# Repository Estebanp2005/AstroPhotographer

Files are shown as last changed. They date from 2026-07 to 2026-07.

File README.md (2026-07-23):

# AstroPhotographer

*Read this in other languages: [Español](README_es.md)*

**AstroPhotographer** is an advanced, automated intervalometer specifically designed for astrophotography. Based on the ESP8266 microcontroller, this device allows precise control of the shutter and focus of DSLR or Mirrorless cameras through a relay system, providing comprehensive management for long photographic sessions.

## Main Features

* **Precise Control:** Management of shutter speeds and intervals between photos via a 2-channel relay module.
* **Profile Management:** Non-volatile storage of up to 6 customizable shooting profiles (name, shutter speed, interval, and photo limit).
* **Intuitive User Interface:** Menu navigation using a rotary encoder and real-time visualization on a 16x2 LCD display (I2C).
* **Global Statistics:** Persistent recording in EEPROM memory (LittleFS/Preferences) of the total historical photos captured and the total running time of the device.
* **Acoustic Notifications:** Integration of an active buzzer for sequence completion alerts.
* **Adaptive Logic:** Software compensation for native reverse logic found in standard relay modules, and hardware/software managed debounce for the rotary encoder.

---

## Hardware Requirements

* ESP8266 Microcontroller (NodeMCU V2/V3 or Wemos D1 Mini).
* 16x2 LCD Display with I2C adapter module.
* Rotary Encoder (Standard 5-pin module or "bare" encoder with internal Pull-Up resistors enabled via software).
* 2-Channel Relay Module (Reverse Logic in this specific build).
* Active Buzzer.
* Camera trigger cable compatible with your specific camera port.
* Logic Level Shifter (3.3V to 5V).

---

## Wiring Schematic (Pinout)

### Hardware Wiring Diagram
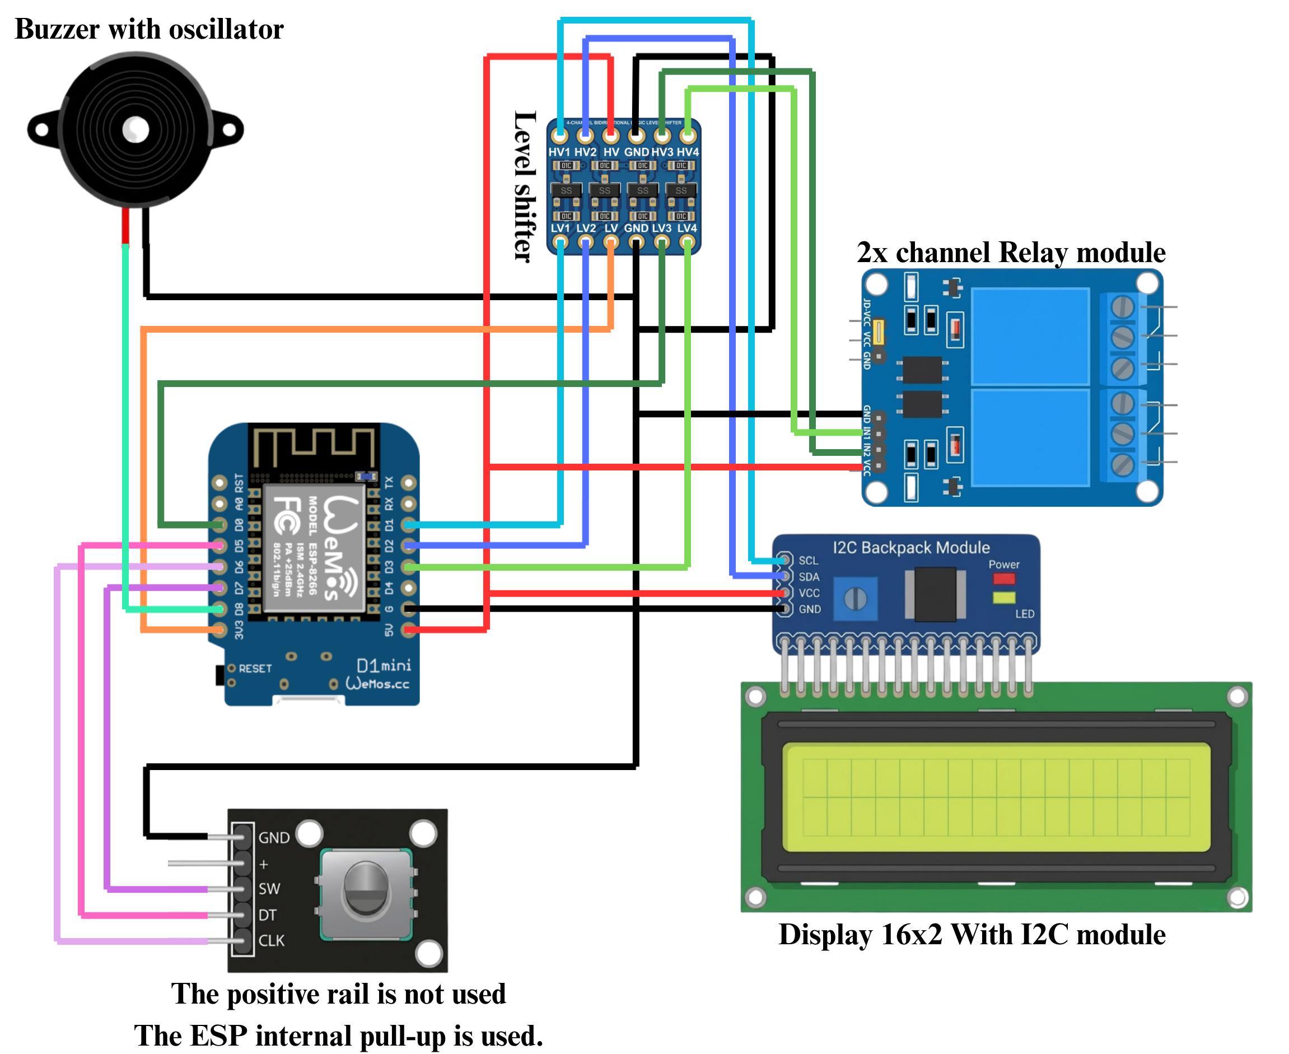
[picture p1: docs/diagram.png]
AstroTracker wiring diagram


### Canon camera jack connection
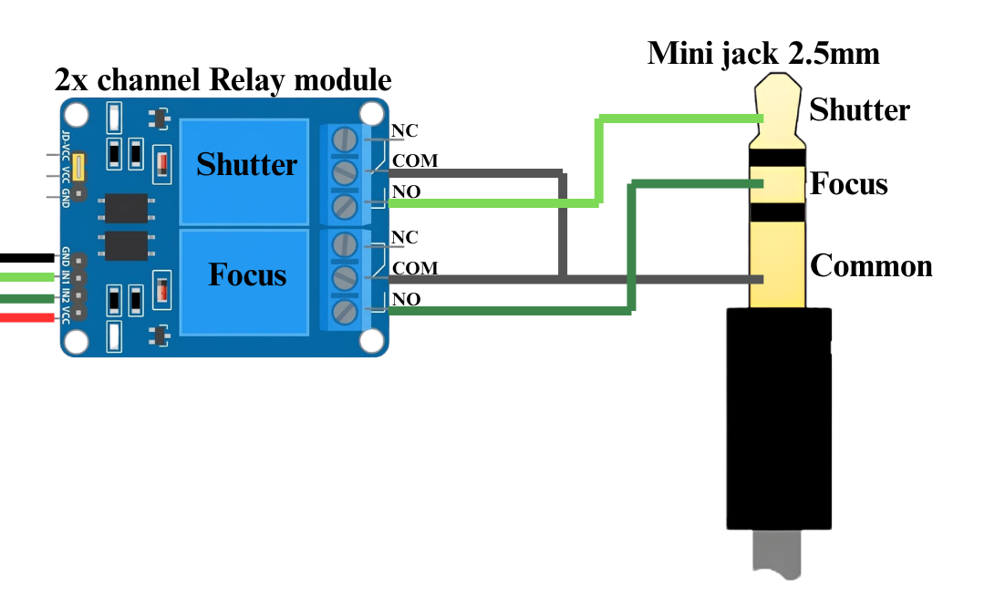
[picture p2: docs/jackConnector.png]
Canon camera jack connection


The following table describes the connection of the peripherals to the ESP8266 GPIO pins according to the firmware configuration:

| Component | Component Pin | ESP8266 Pin |
| :--- | :--- | :--- |
| **LCD Display (I2C)** | SCL | D1 |
| | SDA | D2 |
| **Camera Relays** | Focus IN | D0 |
| | Shutter IN | D3 |
| **Rotary Encoder** | Pin A (DT) | D5 |
| | Pin B (CLK) | D6 |
| | Switch (SW) | D7 |
| **Buzzer**| Positive (VCC/IN) | D8 |

> **Note:** Ensure proper power supply (VCC 3.3V/5V and GND) to the LCD, rotary encoder, and relay module using the board's power outputs or an external regulated power source.

### Hardware assembly
My hardware assembly
| **Perfboard (Top View)** | **Perfboard (Soldering)** | **Case Mounting (1)** |
| :---: | :---: | :---: |
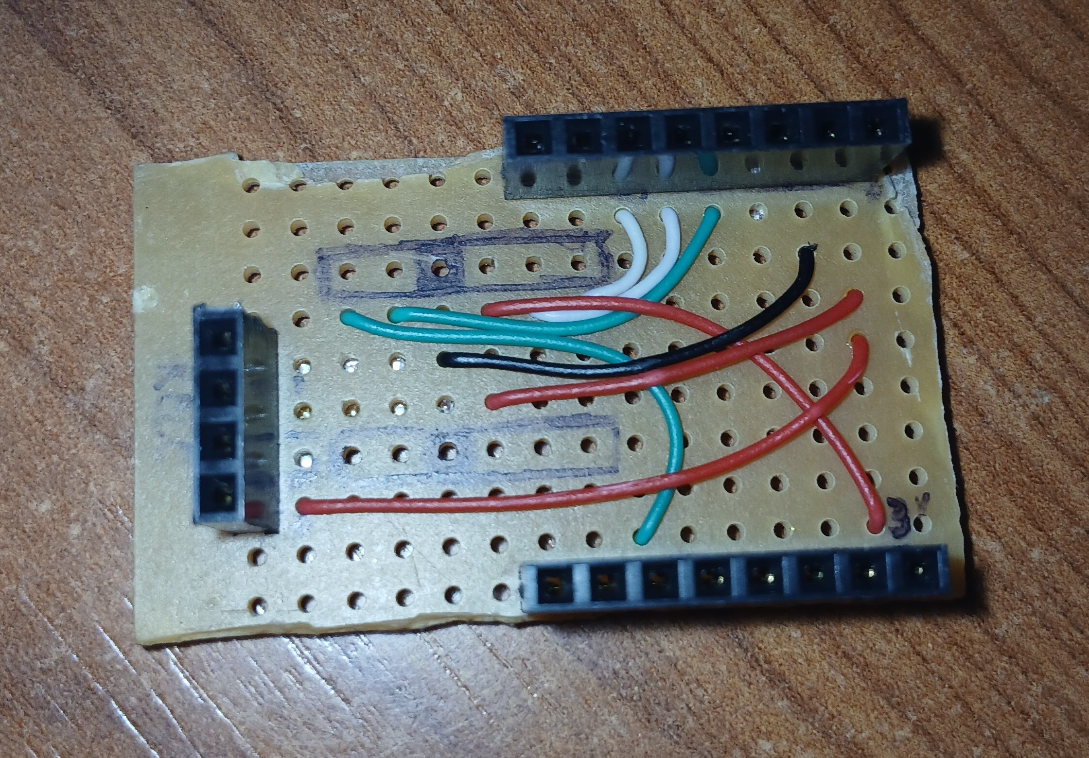
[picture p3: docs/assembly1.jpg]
Top View
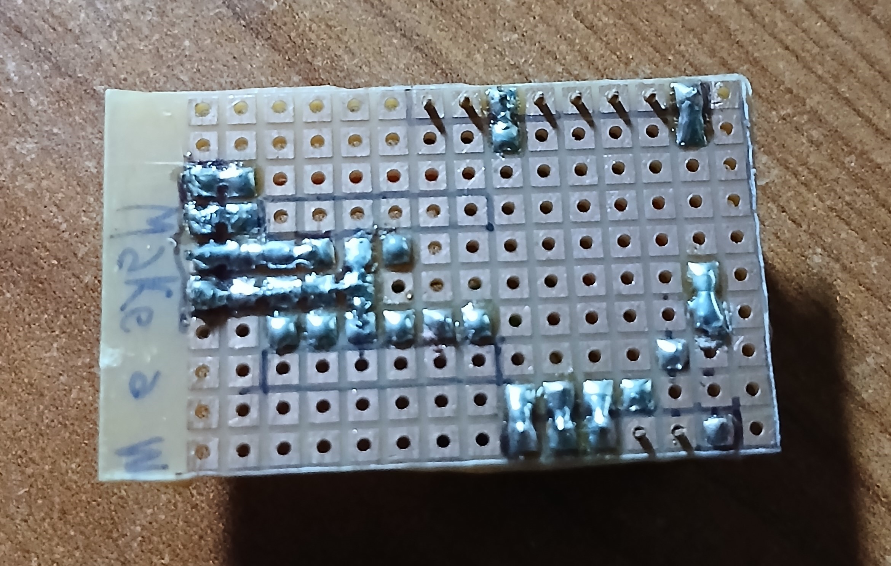
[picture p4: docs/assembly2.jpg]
Soldering
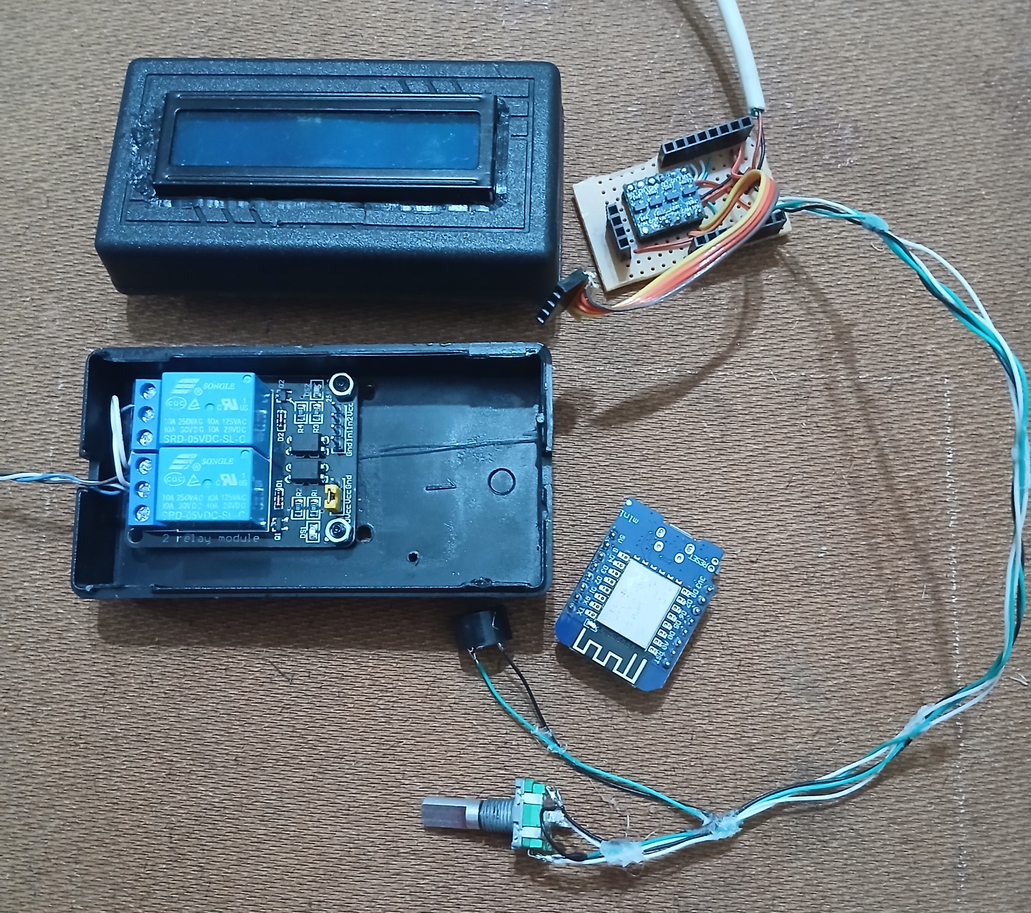
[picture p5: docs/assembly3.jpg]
Layout
|  |  |  |
| **Case Mounting (2)** | **Case Mounting (3)** | **Final Assembly** |
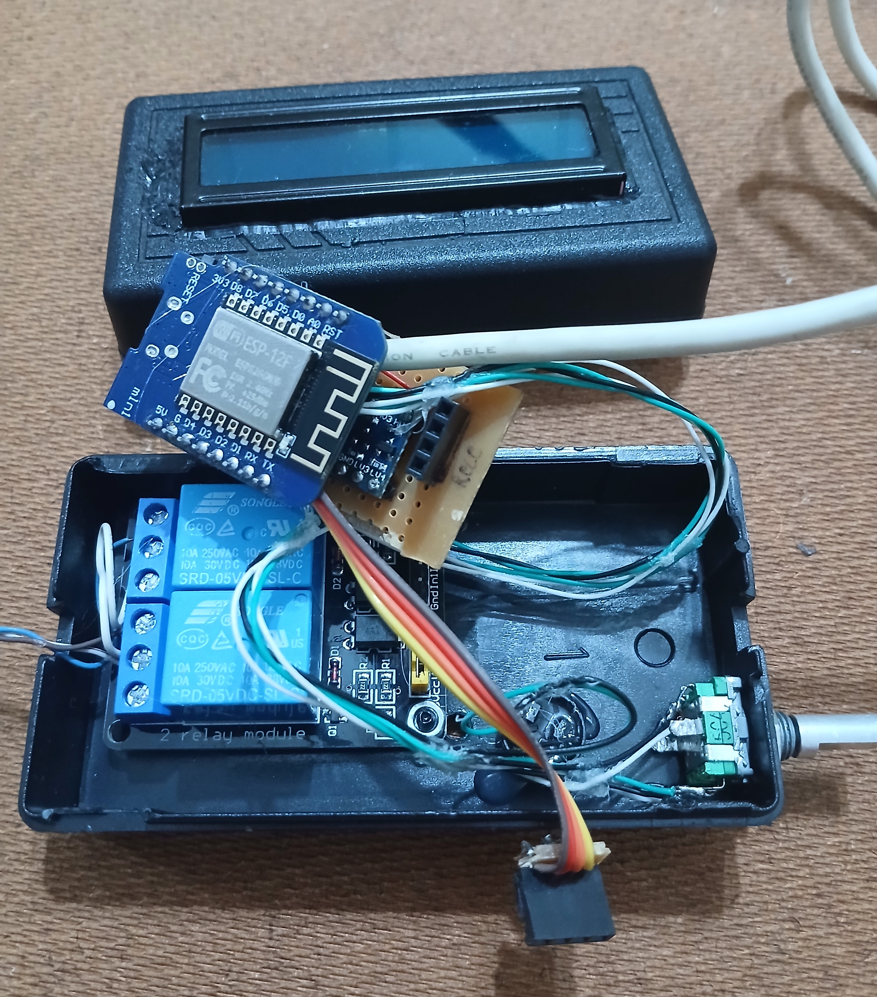
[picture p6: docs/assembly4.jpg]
Mounting 1
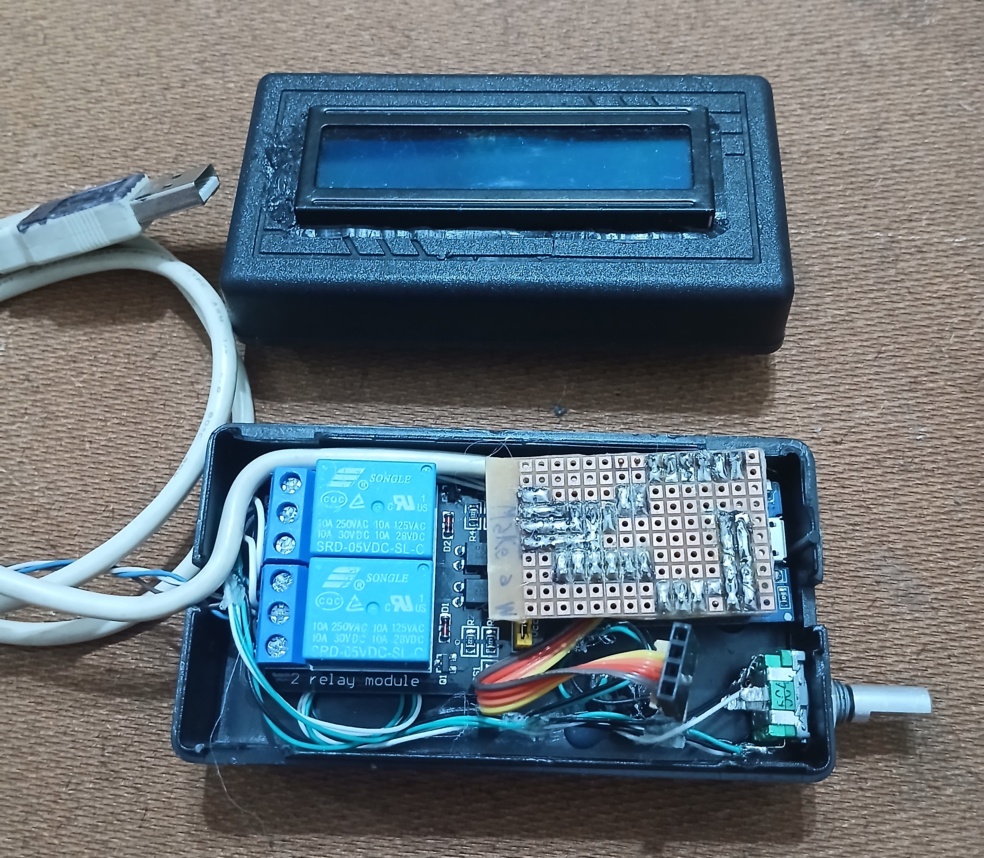
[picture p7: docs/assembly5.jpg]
Mounting 2
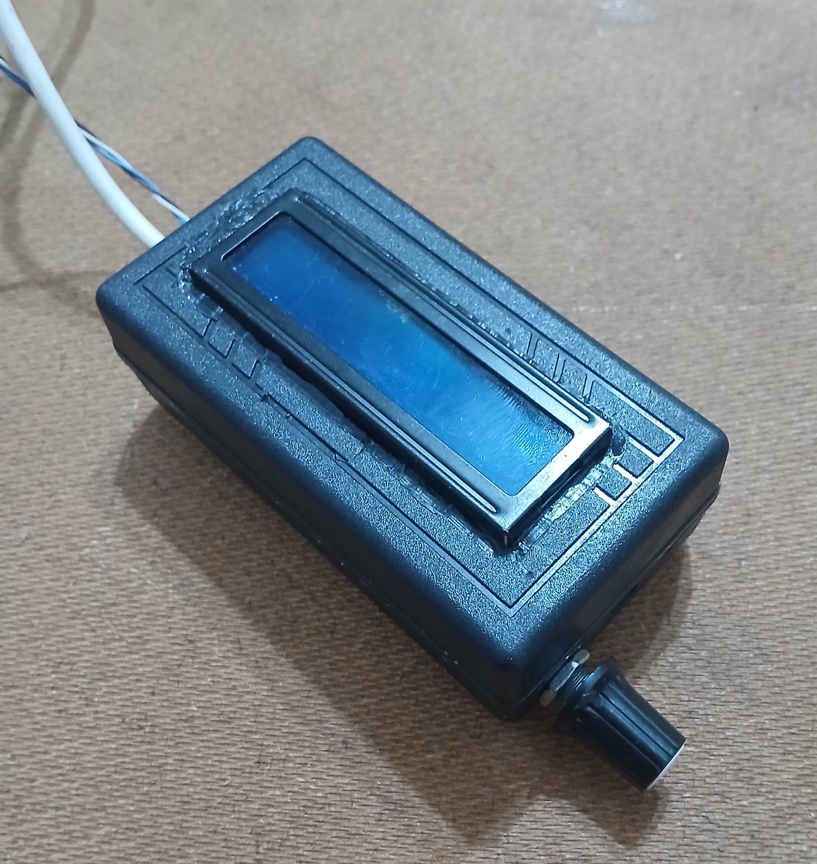
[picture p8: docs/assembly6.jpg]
Final
|  |  |  |

> **Author's note:** I know, this is a bit of a mess; I'm working on a future version that uses Bluetooth instead of a display. Any help is welcome.
---

## Software Dependencies & Libraries

To compile this project in the Arduino IDE, you must install the ESP8266 board support and the following libraries:

1. **[LiquidCrystal_I2C](https://github.com/markub3327/LiquidCrystal_I2C)** (v2.0.0) by Martin Kubovčík / Frank de Brabander: For display management.
2. **[Ai Esp32 Rotary Encoder](https://github.com/igorantolic/ai-esp32-rotary-encoder)** (v1.7) by Igor Antolic: For asynchronous reading and hardware acceleration of the encoder. *(Note: Fully compatible with ESP8266 despite its name).*
3. **[Preferences](https://github.com/vshymanskyy/Preferences)** (v2.2.2) by Volodymyr Shymanskyy: Used to emulate secure EEPROM writing via the LittleFS file system.

---

## Menu Flowchart

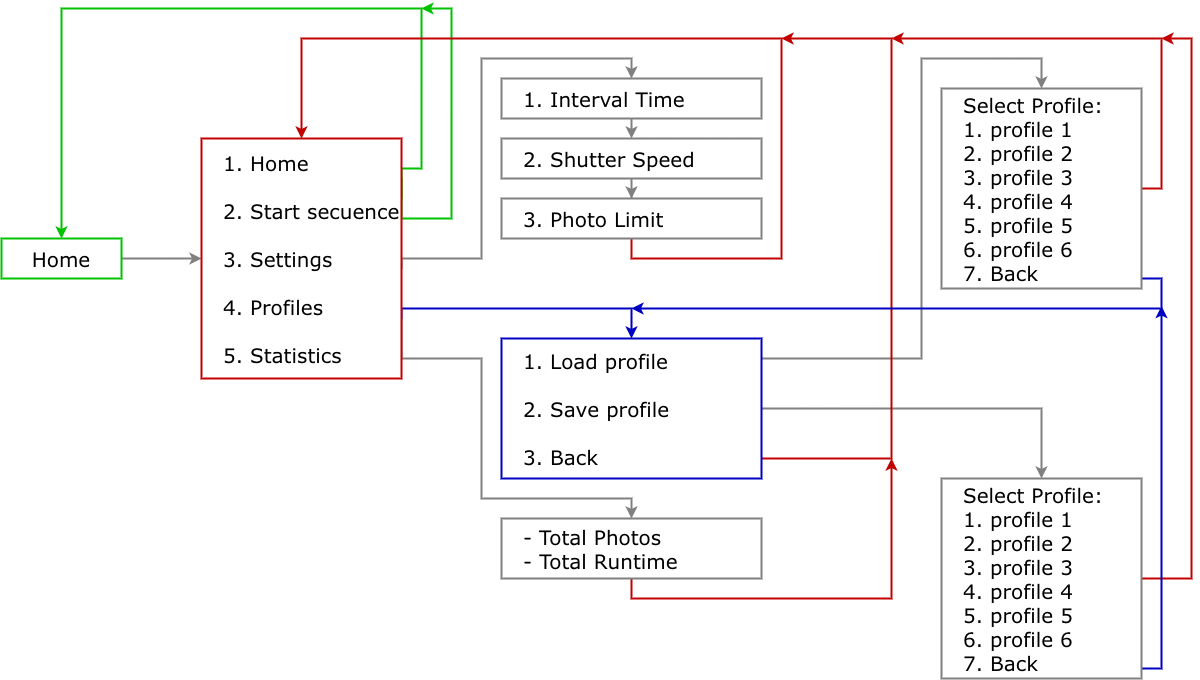
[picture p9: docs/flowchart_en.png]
AstroTracker Menu Flowchart


---

## Usage and Navigation

The system is operated entirely through the rotary encoder (Rotate to navigate/adjust, Press to select).

* **Main Menu:** Access to start sequence, manual configuration, profile loading/saving, and statistics visualization.
* **Start Sequence:** Allows forcing the focus (clockwise rotation) or taking a test shot (counter-clockwise rotation) before starting automation. During the session, the display shows a progress bar and elapsed time.
* **Configuration:** Real-time adjustment of shutter time, interval between photos, and capture limit (0 = infinite).
* **Profiles:** The system allows editing each profile's name character by character for easy identification of photographic setups (e.g., "Milky Way", "Startrails").

---

## Installation

### 1. Board Manager Setup
If you haven't already, add the ESP8266 board support to your Arduino IDE:
* Go to **File > Preferences**.
* In "Additional Boards Manager URLs", add: `https://arduino.esp8266.com/stable/package_esp8266com_index.json`
* Go to **Tools > Board > Boards Manager**, search for `esp8266` and install it.

### 2. Flashing the Firmware
1. Clone this repository.
2. Open the main file `Astrophotographer.ino` in the Arduino IDE.
3. Install the libraries mentioned in the dependencies section via the Library Manager (`Ctrl+Shift+I`).
4. Select your specific ESP8266 board in **Tools > Board**.
5. Compile and upload the firmware to the microcontroller.

---

## License

This project is licensed under the [GNU General Public License v3.0](LICENSE) - see the LICENSE file for details.

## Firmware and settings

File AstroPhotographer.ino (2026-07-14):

/**
 * @file Astrophotographer.ino
 * @brief Main entry point for the AstroTracker firmware.
 * * This file handles the core initialization and the main execution loop
 * of the astrophotography intervalometer. It delegates specific tasks 
 * (input processing, camera relay control, display UI, and memory storage) 
 * to their respective modular components.
 */

#include "Config.h"
#include "Input.h"
#include "Camera.h"
#include "Display.h"
#include "Storage.h"

// --- Global Variables Instantiation ---

/**
 * @brief Tracks the current operational state of the system 
 * (e.g., IDLE, MENU, CONFIG, RUNNING_SEQUENCE).
 */
SystemState currentState = ESTADO_INICIO;

/**
 * @brief Holds the currently active shooting profile loaded in RAM
 * (includes interval, exposure time, photo limit, and profile name).
 */
Perfil perfilActual;

/**
 * @brief Stores the global usage statistics tracked across reboots 
 * (total device runtime and total historical photos taken).
 */
Estadisticas statsGlobales;

/**
 * @brief Navigation index for the primary menu selection.
 */
int menuIndex = 0;

/**
 * @brief Navigation index for the configuration sub-menus.
 */
int configIndex = 0;

// --- Core Functions ---

/**
 * @brief System initialization routine.
 * * Sets up serial communication, initializes the non-volatile storage, 
 * loads the default profile, and prepares all hardware peripherals.
 */
void setup() {
  // Initialize serial communication for debugging purposes
  Serial.begin(115200);
  
  // Initialize LittleFS/Preferences and load historical stats from EEPROM
  initStorage(); 
  
  // Load the default shooting profile (Slot 1 / Index 0) into RAM on startup
  cargarPerfil(0); 
  
  // Initialize hardware peripherals and internal software modules
  initInput();
  initCamera();
  initDisplay();
}

/**
 * @brief Main execution loop.
 * * Continuously polls the encoder input, updates the camera relay logic 
 * based on the active sequence, and refreshes the LCD display UI. 
 * This loop relies on non-blocking state machines.
 */
void loop() {
  updateInput();
  updateCamera();
  updateDisplay();
}

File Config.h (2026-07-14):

/**
 * @file Config.h
 * @brief Global configuration, hardware pinout, data structures, and state machines.
 * * This header acts as the central source of truth for the entire project, 
 * defining hardware connections, UI states, camera sequence states, and data models.
 */

#ifndef CONFIG_H
#define CONFIG_H

#include <Arduino.h>

// --- HARDWARE PINOUT ---

// I2C Display Pins
#define PIN_SCL D1
#define PIN_SDA D2

// Rotary Encoder Pins
#define PIN_ENC_A D5     // DT (Data)
#define PIN_ENC_B D6     // CLK (Clock)
#define PIN_ENC_SW D7    // Switch/Button

// Relay Module & Buzzer Pins
#define PIN_RELAY_SHUTTER D3
#define PIN_RELAY_FOCUS D0
#define PIN_BUZZER D8

// --- DATA STRUCTURES ---

/**
 * @brief Represents a single astrophotography shooting profile.
 */
struct Perfil {
  char nombre[15];          /**< Profile name (max 14 chars + null terminator) */
  float tiempoEntreFotos;   /**< Interval between shots in seconds */
  float tiempoObturacion;   /**< Exposure time in seconds */
  int limiteFotos;          /**< Number of photos to take (0 = infinite) */
};

/**
 * @brief Global device statistics persisted in non-volatile memory (EEPROM/LittleFS).
 */
struct Estadisticas {
  unsigned long totalFotosHistorico; /**< Total photos taken across all sessions */
  unsigned long tiempoTotalFunc;     /**< Total device runtime in milliseconds */
};

// --- STATE MACHINES ---

/**
 * @brief Enumerates the possible states of the user interface (UI).
 */
enum SystemState { 
  ESTADO_INICIO,         /**< Idle / Home screen */
  ESTADO_MENU_PRINCIPAL, /**< Main menu navigation */
  ESTADO_CONFIG,         /**< Adjusting current profile parameters */
  ESTADO_MENU_PERFILES,  /**< Selecting profile management options */
  ESTADO_CARGAR_PERFIL,  /**< Loading a profile from storage */
  ESTADO_GUARDAR_PERFIL, /**< Selecting a slot to save the current profile */
  ESTADO_EDITAR_NOMBRE,  /**< Character-by-character name editing */
  ESTADO_ESTADISTICAS    /**< Viewing historical stats */
};

/**
 * @brief Enumerates the possible states of the camera trigger sequence.
 */
enum CameraState { 
  CAM_DETENIDO,       /**< Sequence stopped / inactive */
  CAM_ESPERA_INICIAL, /**< Initial 3-second delay before starting the sequence */
  CAM_ENFOCANDO,      /**< Active focus trigger (if used in sequence) */
  CAM_OBTURANDO,      /**< Active shutter trigger (exposure) */
  CAM_INTERVALO       /**< Waiting interval between exposures */
};

// --- GLOBAL VARIABLES (External Declarations) ---

extern SystemState currentState;
extern CameraState camState;
extern Perfil perfilActual;
extern Estadisticas statsGlobales;
extern int menuIndex;
extern unsigned long tiempoInicioSesion;
extern int configIndex;

// --- CONSTANTS ---

/** * @brief Available characters for naming profiles in the UI. 
 * Note the first character is a blank space.
 */
const char ALFABETO[] = " ABCDEFGHIJKLMNOPQRSTUVWXYZ0123456789-/.";

#endif // CONFIG_H

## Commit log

2026-07-11 Add core functionality and state management for camera control
2026-07-12 Refactor camera logic for manual and automatic modes
2026-07-12 Implement obtenerNombrePerfil function
    Add function to retrieve profile name based on slot.
2026-07-12 Fix formatting and reorder extern declarations in Config.h
    [Config.h]
2026-07-12 Update camera control flow and remove manual functions
    Refactor camera control logic and remove manual calibration functions.
2026-07-12 Refactor Camera.h to include updateCamera function
2026-07-12 Add duration variable for last session in Camera.h
2026-07-12 Add duration tracking for the last camera session
    Added a new global variable to track the duration of the last session and updated the logic to calculate it when stopping the sequence.
2026-07-12 Refactor time tracking logic in ESTADO_INICIO case
    Replaced static variable with a regular variable for time tracking and adjusted logic for displaying time based on camera state.
    [Display.cpp]
2026-07-12 Actualizar Camera.cpp
2026-07-14 Fix type casting for session duration calculation
    [Camera.cpp]
2026-07-14 Refactor relay control logic in Camera.cpp
    Updated relay logic to use HIGH for off and LOW for on.
2026-07-14 Initialize buzzer and add alarm sound function
    Added buzzer initialization and alarm sound function.
    [Camera.cpp]
2026-07-14 Update README.md with project details and instructions
    Added detailed project description, features, hardware requirements, connection schematic, dependencies, usage instructions, and installation steps for AstroTracker.
2026-07-14 Añadido flowchart_es.png
2026-07-14 Actualizar flowchart_es.png
2026-07-14 Añadido flowchart_en.png
2026-07-14 Actualizar flowchart_en.png
2026-07-14 Flowchart chages
2026-07-14 Update flowchart image for Spanish README
2026-07-14 Refactor camera control logic and add buzzer alerts
    [Camera.cpp]
2026-07-14 Enhance Camera.h with detailed documentation
    Added documentation comments for clarity and understanding of the camera control module functions.
2026-07-14 Enhance Input.h with documentation and prototypes
    Added documentation and function prototypes for rotary encoder input handling.
2026-07-14 Enhance Storage.h with NVS function prototypes
    Added function prototypes for managing non-volatile storage on the ESP8266, including initialization, statistics management, and profile handling.
2026-07-14 Added schematic
    [AstroPhotographer.kicad_sch]
2026-07-15 Update README with wiring diagrams and connections
    Added hardware wiring diagram and Canon camera jack connection images to README.
2026-07-23 Add hardware assembly details to README
    Added hardware assembly section with images and notes.
2026-07-23 Fix typo in 'Hardware assembly' section
2026-07-23 Add hardware assembly instructions to README_es.md
    Added hardware assembly section with images.
2026-07-24 add assembly images
